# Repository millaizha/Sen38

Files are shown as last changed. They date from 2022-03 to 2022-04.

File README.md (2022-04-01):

# Sen38
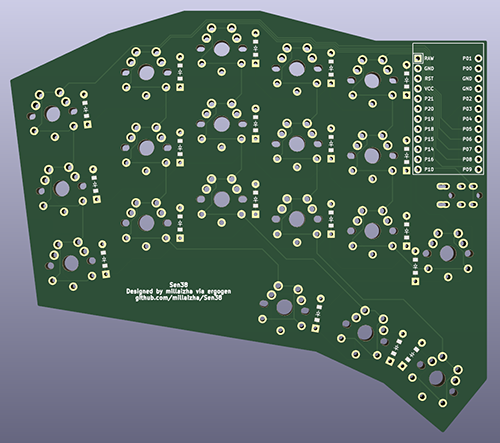
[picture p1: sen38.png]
Sen38
  

The Sen38 is 38-key split column stagger keyboard with pinky splay. 
Made using [ergogen](https://ergogen.xyz)

This keyboard is MX and Choc compatible.

## Notes

* .yaml does not include edge cuts. May need to add it in KiCAD.
* Changed some placements of the diodes in KiCAD.
* Will try to make the connections look better soon.
* Firmware to be added soon in my [QMK fork](https://github.com/millaizha/qmk_firmware).

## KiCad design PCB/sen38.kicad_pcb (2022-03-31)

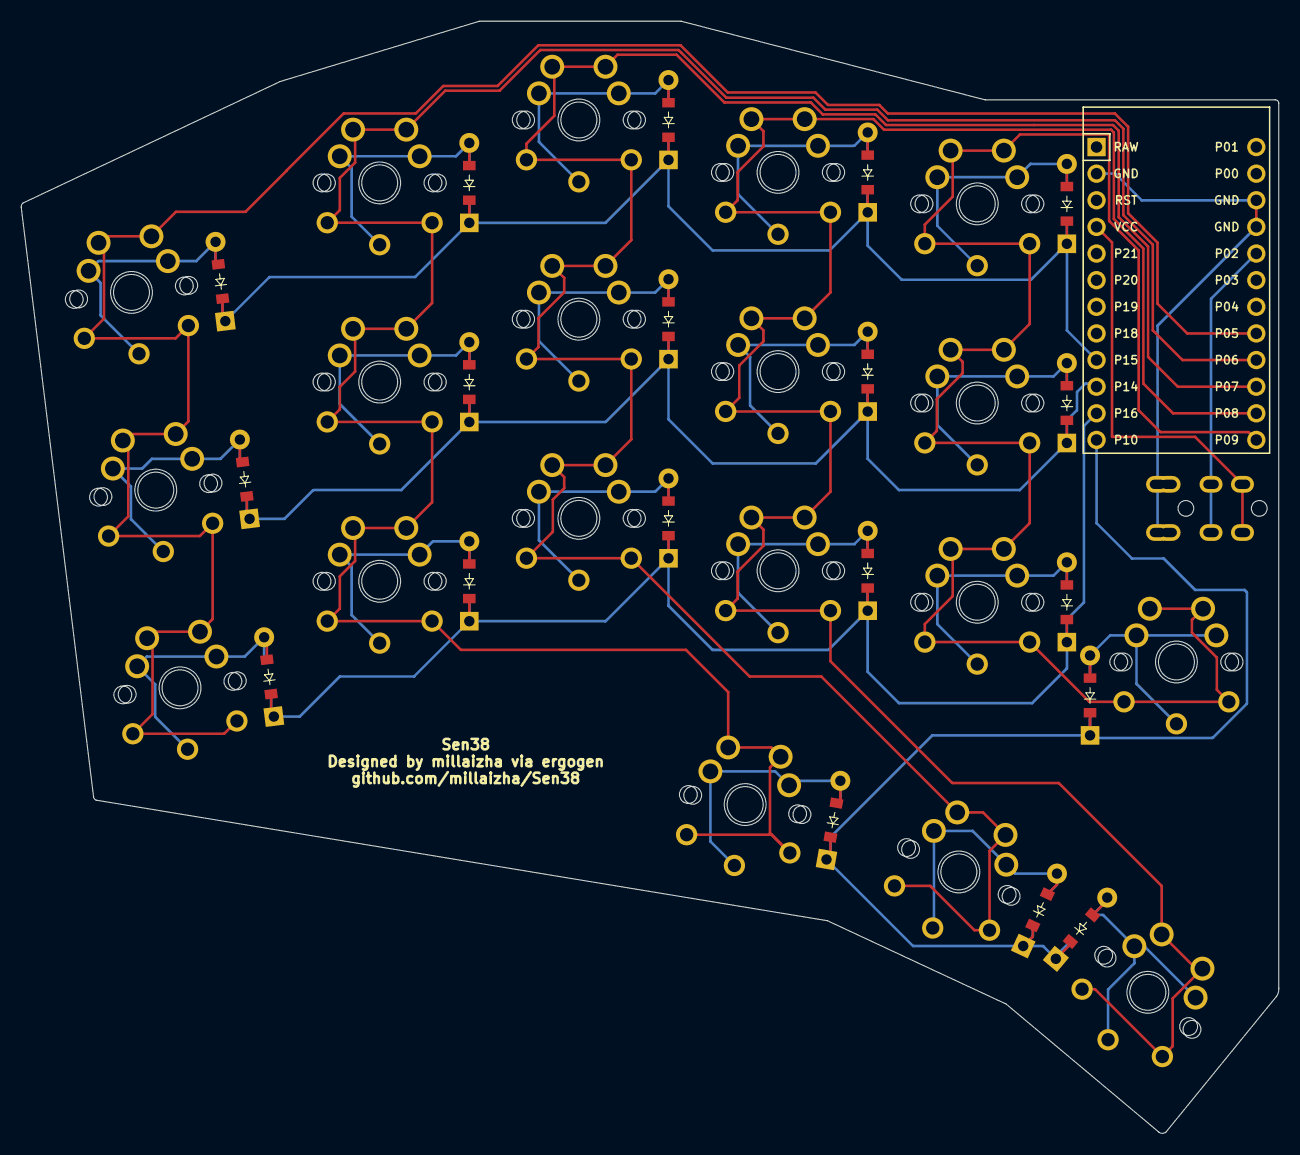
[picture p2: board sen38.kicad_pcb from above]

Board: 2 copper layers, 120.0 x 106.1 mm, 58 parts (0 on the bottom side), 29 nets.

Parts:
D1, D2, D3, D4, D5, D6, D7, D8, D9, D10, D11, D12, D13, D14, D15, D16, D17, D18, D19: ComboDiode
MCU1: ProMicro
S1, S3, S5, S7, S9, S11, S13, S15, S17, S19, S21, S23, S25, S27, S29, S31, S33, S35, S37: MX
S2, S4, S6, S8, S10, S12, S14, S16, S18, S20, S22, S24, S26, S28, S30, S32, S34, S36, S38: PG1350

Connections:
GND: MCU1.2, MCU1.15, MCU1.16
P5: MCU1.20, S1.1, S2.1, S3.1, S4.1, S5.1, S6.1
P6: MCU1.21, S7.1, S8.1, S9.1, S10.1, S11.1, S12.1, S31.1, S32.1
P7: MCU1.22, S13.1, S14.1, S15.1, S16.1, S17.1, S18.1, S33.1, S34.1
P8: MCU1.23, S19.1, S20.1, S21.1, S22.1, S23.1, S24.1, S35.1, S36.1
P9: MCU1.24, S25.1, S26.1, S27.1, S28.1, S29.1, S30.1, S37.1, S38.1
P10: D16.1, D16.2, D17.1, D17.2, D18.1, D18.2, D19.1, D19.2, MCU1.12
P14: D2.1, D2.2, D5.1, D5.2, D8.1, D8.2, D11.1, D11.2, D14.1, D14.2, MCU1.10
P15: D3.1, D3.2, D6.1, D6.2, D9.1, D9.2, D12.1, D12.2, D15.1, D15.2, MCU1.9
P16: D1.1, D1.2, D4.1, D4.2, D7.1, D7.2, D10.1, D10.2, D13.1, D13.2, MCU1.11
bottom_home: D19.1, D19.2, S37.2, S38.2
far_home: D18.1, D18.2, S35.2, S36.2
home_home: D17.1, D17.2, S33.2, S34.2
index_bottom: D10.1, D10.2, S19.2, S20.2
index_home: D11.1, D11.2, S21.2, S22.2
index_top: D12.1, D12.2, S23.2, S24.2
inner_bottom: D13.1, D13.2, S25.2, S26.2
inner_home: D14.1, D14.2, S27.2, S28.2
inner_top: D15.1, D15.2, S29.2, S30.2
middle_bottom: D7.1, D7.2, S13.2, S14.2
middle_home: D8.1, D8.2, S15.2, S16.2
middle_top: D9.1, D9.2, S17.2, S18.2
near_home: D16.1, D16.2, S31.2, S32.2
pinky_bottom: D1.1, D1.2, S1.2, S2.2
pinky_home: D2.1, D2.2, S3.2, S4.2
pinky_top: D3.1, D3.2, S5.2, S6.2
ring_bottom: D4.1, D4.2, S7.2, S8.2
ring_home: D5.1, D5.2, S9.2, S10.2
ring_top: D6.1, D6.2, S11.2, S12.2

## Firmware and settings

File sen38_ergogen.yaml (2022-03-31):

points:
  zones:
    matrix:
      columns:
        pinky:
          stagger: 4
          rotate: 7
          rows:
            home.bind: [0,10,5,0]
            top.bind: [10,10,10,0]
            bottom.bind: [0,1,0,2]
          key:
            column_net: P5
        ring:
          stagger: 9
          spread: U
          origin: [-0.5U, -0.5U]
          rotate: -7
          rows:
            home.bind: [0,10,10,0]
            top.bind: [10,10,10,0]
            bottom.bind: [0,1,0,2]
          key:
            column_net: P6
        middle:
          stagger: 6
          rows:
            home.bind: [0,10,10,0]
            top.bind: [10,10,10,0]
            bottom.bind: [0,10,0,1]
          key:
            column_net: P7
        index:
          stagger: -5
          rows:
            home.bind: [0,10,10,0]
            top.bind: [10,10,10,0]
            bottom.bind: [0,10,0,1]
          key:
            column_net: P8
        inner:
          stagger: -3
          rows:
            home.bind: [0,0,10,0]
            top.bind: [10,0,10,0]
            bottom.bind: [0,0,0,0]
          key:
            column_net: P9
      rows:
        bottom:
          bind: [10]
          row_net: P16
        home:
          bind: [10]
          row_net: P14
        top:
          row_net: P15
    thumb:
      anchor:
        ref: matrix_index_bottom
        shift: [ -1.15u, -u ]
        rotate: -10
      columns:
        near:
          spread: 19
          key:
            column_net: P6
        home:
          spread: U
          rotate: -15
          origin: [-0.5U, -0.5U]
          key:
            column_net: P7
        far:
          spread: U
          rotate: -15
          origin: [-0.5U, -0.5U]
          key:
            column_net: P8
      rows:
        home:
          bind: [10,0,0,0]
          padding: 0
          row_net: P10
    extra:
      anchor:
        ref: matrix_inner_bottom
        shift: [u,-0.3u]
      columns:
        bottom:
          key:
            column_net: P9
      rows:
        home:
          padding: 0
          row_net: P10
        
  key:
    footprints:
      diode:
        type: diode
        nets:
          from: =colrow 
          to: =row_net
        anchor:
          shift: [0.45u,0]
          rotate: 90
        params:
          through_hole: false
      mx:
        type: mx
        nets:
          from: =column_net
          to: =colrow
        params:
            keycaps: true
            reverse: true
            hotswap: false
      choc:
        type: choc
        anchor:
          rotate: 180
        nets:
          from: =column_net
          to: =colrow
        params:
            keycaps: true
            reverse: true
            hotswap: false
pcbs:
  sen38:
    footprints:
      promicro:
        type: promicro
        anchor:
          ref: matrix_inner_home
          shift: [19, 0.55u]
          rotate: -90
        params:
          orientation: down
      trrs:
        type: trrs
        nets:
          A: GND
          B: GND
          C: P2
          D: VCC
        anchor:
          ref: matrix_inner_bottom
          shift: [1.5u, 0.35u]
          rotate: -90
        params:
          reverse: true
          symmetric: true
